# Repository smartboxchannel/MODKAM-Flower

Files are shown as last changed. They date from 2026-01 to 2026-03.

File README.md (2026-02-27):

# MODKAM Flower

## Открытый проект датчика влажности почвы MODKAM Flower v4

(основан на исходном коде проекта DIYRUZ Flower - https://github.com/diyruz/flower)

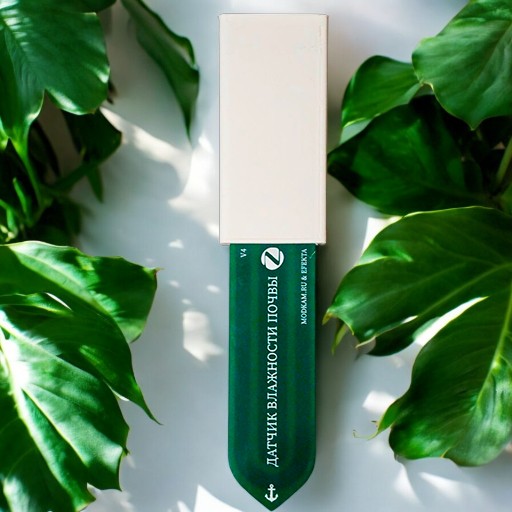
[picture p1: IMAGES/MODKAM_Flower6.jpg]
MODKAM Flower
 

Датчик, работает на базе SoC CC2530, основан на емкостном методе измерения (у датчика нет электрического контакта с почвой). Питание датчика осуществляется от батареек CR 2032 и AAA.

Печатная плата четырехслойная, с медным сенсором во внутреннем слое. Это решение обеспечивает долговечность. Медный сенсор со временем не коррозирует от проникающей влаги через микротрещины в маске, которые появляются со временем.

### Основные передаваемые данные:

Identify - идентификация устройства

Soil moisture - измеренное значение влажности почвы

Battery - оставшийся заряд в %

### Дополнительные передаваемые данные:

Temperature - измеренное значение температуры

Illuminance - измеренная освещенность(версия zFlora S Max)

Устройство может быть сконфигурировано внешними командами, отправляемыми через интерфейс контроллера умного дома. 

Что бы датчик получило конфигурационную команду, после отправки нового значения со страницы устройства в з2м, нужно нажать кнопку на датчике, он выйдет из сна, примет данные и запишет в энергонезависимую память.

### Конфигурационные команды:

Read sensors delay - время сна датчика, в минутах, по умолчанию 3 минуты

Smart sleep - Режим проверки устройством наличия для него пакетов на роутерах и координаторе

Lifetime - время работы датчика с момента прошивки

Tx radio power - Мощность радиопередатчика

Resolution - Разрешение сенсора DS18B20

Temperature compensation - Температурная компенсация

Lux factor - множитель для подстройки сенсора освещенности, диапазон 0.1-10.0, шаг 0.1.

#

### Ввод датчика в сеть, выход из сети
Для джойна (вход в сеть), нажать и удерживать кнопку 2 секунды, загорится светодиод, потухнет либо при начале входа в сеть, (в среднем через 5-8 секунд) либо через 15 секунд, что будет означать что датчик не нашел открытой сети.

На время ввода в сеть расположитесь не далеко от координатора (1-2 метра) или роутера с хорошим уровнем сигнала. 

Если вы не видите на вкладке свойства всех значений конфигурационных атрибутов(пустые поля, переключатели в неопределенном состоянии) или на странице отчеты нет строк о батарейке, температуре, то скорее всего конфигурация, которая следует сразу за интервью, не была пройдена до конца.

Для повторного прохождения конфигурации, перейдите на главную страницу z2m, найдите строку датчика и справа нажмите на кнопку - реконфигурация (желтая кнопка), после этого нажмите 2-5 раз кнопку на датчике с интервалом 1-2 секунды. При успешном прохождении конфигурации в интерфейсе з2м должно появится "всплывающее" сообщение об успешно пройденной реконфигурации. В разделе датчика, на вкладке свойства должны появится значения и установки всех конфигурационных свойств, на странице отчеты должны появится строки с конфигурационными настройками отчетов.

Для выхода из сети зажать кнопку на 10 секунд, по истечении этого времени загорится светодиод, кнопку можно отпустить. Датчик отправит сообщение о выходе из сети, сотрет у себя все настройки в памяти.

### Рекомендации
При начальном использовании датчика рекомендуется вставить датчик в грунт и обильно пролить. Что бы из почвы вокруг сенсора вышел воздух и грунт уплотнился. Если этого не сделать, то в первые 1-2 суток может наблюдаться более низкий уровень измеренной влажности, который к тому же может расти немного вверх.

### Тест сенсора влажности

Возьмите датчик в руку (держаться за батарейный отсек, не за плату!).

Не касаясь сенсора нажать кнопку - soil_moisture должно быть 0%.

Зажать второй рукой сенсор, или опустить сенсор в воду, нажать на кнопку - должно быть около больше 0% (в воде 100%).

#

Поблагодарить авторов: https://yoomoney.ru/fundraise/P2XLTgJsB6k.231012

Thank the authors: https://yoomoney.ru/fundraise/P2XLTgJsB6k.231012

Телеграм чат DIY Devices - https://t.me/diy_devices

Продажа DIY Устройств - https://t.me/diydevmart

#

### Установка среды разработки

В качестве среды разработки будет использоваться IAR Embedded Workbench, где цифра 8051 это архитектура чипа, а не версия системы, как можно подумать. Для начала необходимо ее [скачать по ссылке](https://www.iar.com/iar-embedded-workbench#!?architecture=8051)

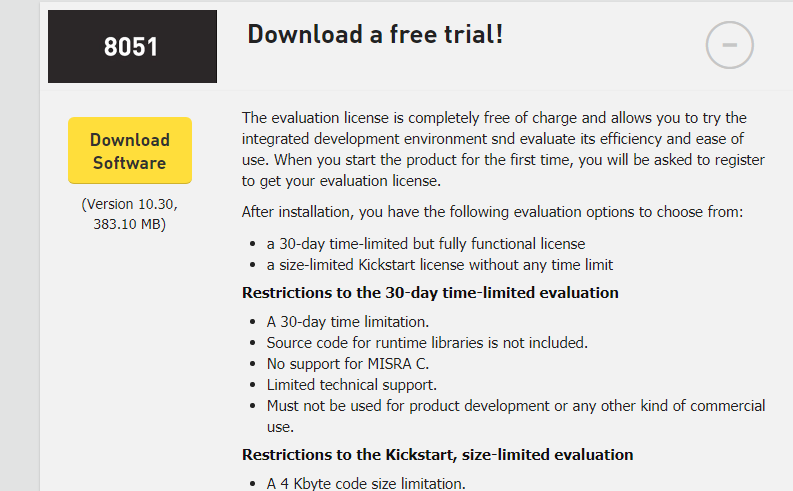
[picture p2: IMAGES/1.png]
 

Запускаем, необходимо выбрать пункт "Install IAR Embedded Workbench® for 8051"

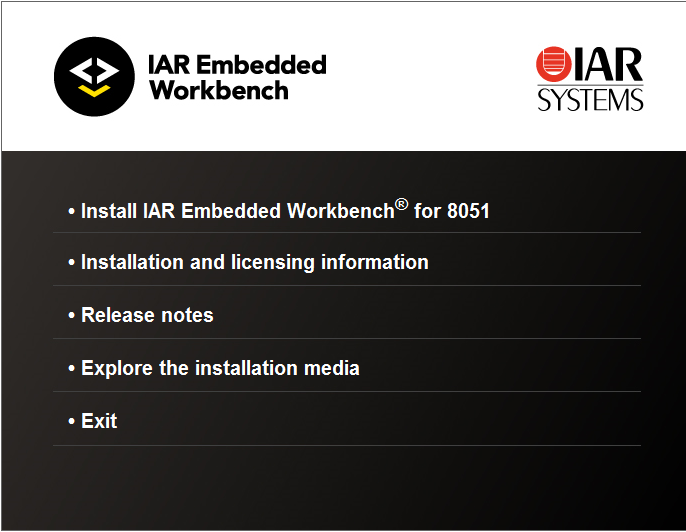
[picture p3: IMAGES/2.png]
 

При установке iar надо выбрать режим custom:

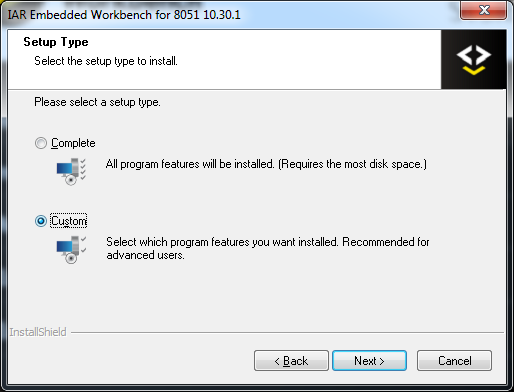
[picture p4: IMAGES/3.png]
 

и убрать галочку с установки Dongle drivers

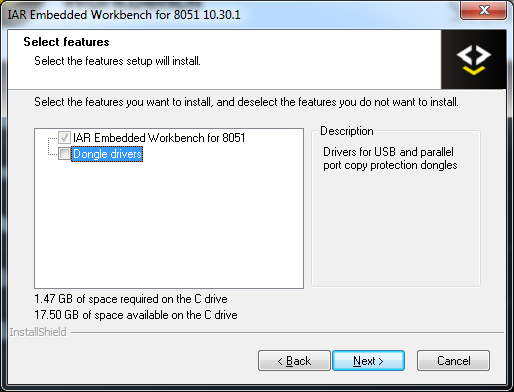
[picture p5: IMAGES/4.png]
 

При попытки запуска проекта может быть такая ошибка:

MODKAM Flower 

Поэтому перед запуском проекта необходимо убедиться что python установлен. Проверить это можно в командной строке:

python –-version

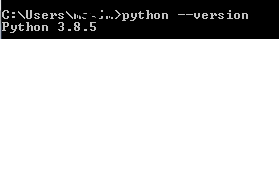
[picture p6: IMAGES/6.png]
 

Если все хорошо, то покажет текущую установленную версию python, как на примере:

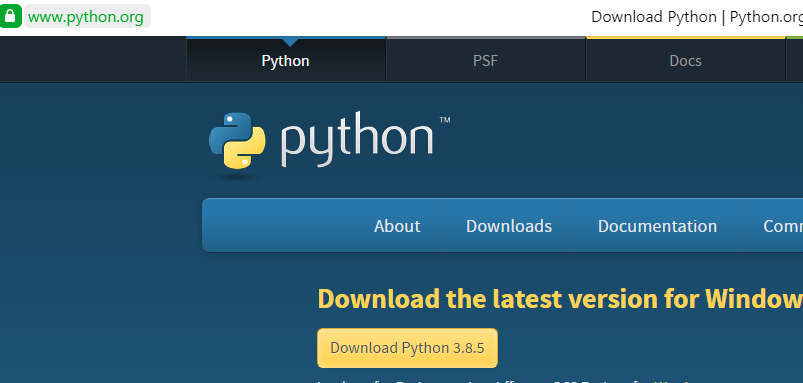
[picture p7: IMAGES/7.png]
 

Если же нет, то [идем устанавливать python](https://www.python.org/)

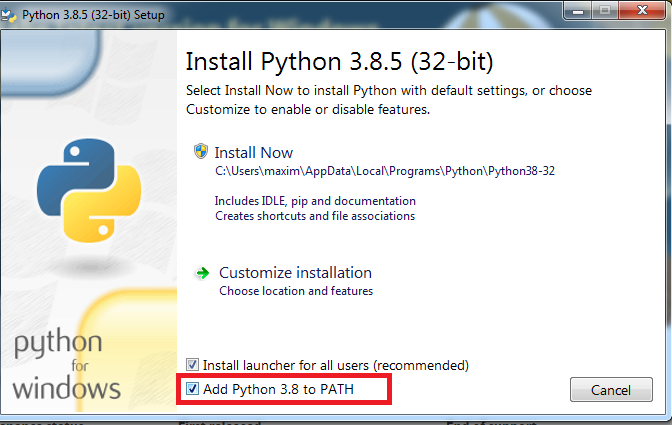
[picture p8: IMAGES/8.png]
 

Устанавливаем его. Обязательно необходимо проставить галочку "add python **** to path"

MODKAM Flower 

Устанавливаем прошивку [Z-Stack 3.0.2](https://www.ti.com/tool/Z-STACK) — это SDK для разработки прошивок.

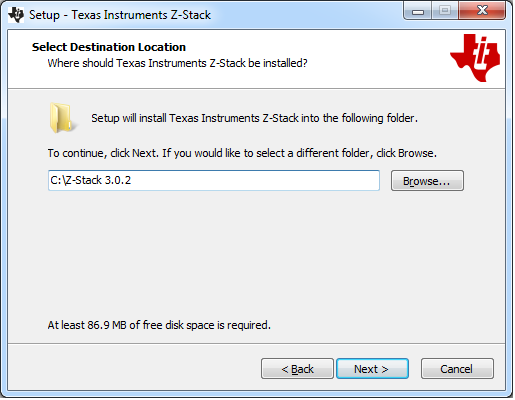
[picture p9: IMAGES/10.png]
 

Устанавливаем, можно немного уменьшить путь до zstack: C:\Z-Stack 3.0.2. 

Скачиваем исходный код из репозитория

Добавляем папку с файлами проекта в zstack: C:\Z-Stack 3.0.2\Projects\zstack\HomeAutomation

Теперь можно запускать IAR Embedded Workbench. Открываем проект пунктом меню Open workspace

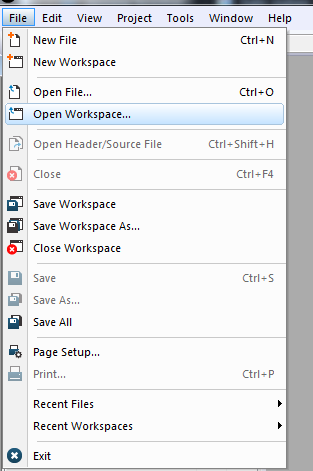
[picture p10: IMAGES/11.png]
 

Находим нашу папку со скаченным проектом, далее в папке CC2530DB находим файл проекта

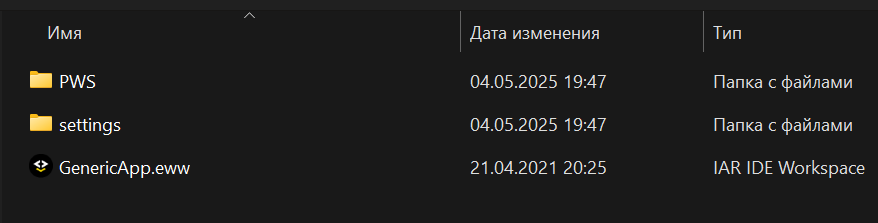
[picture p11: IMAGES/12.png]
 

Выполняем Rebuild All.

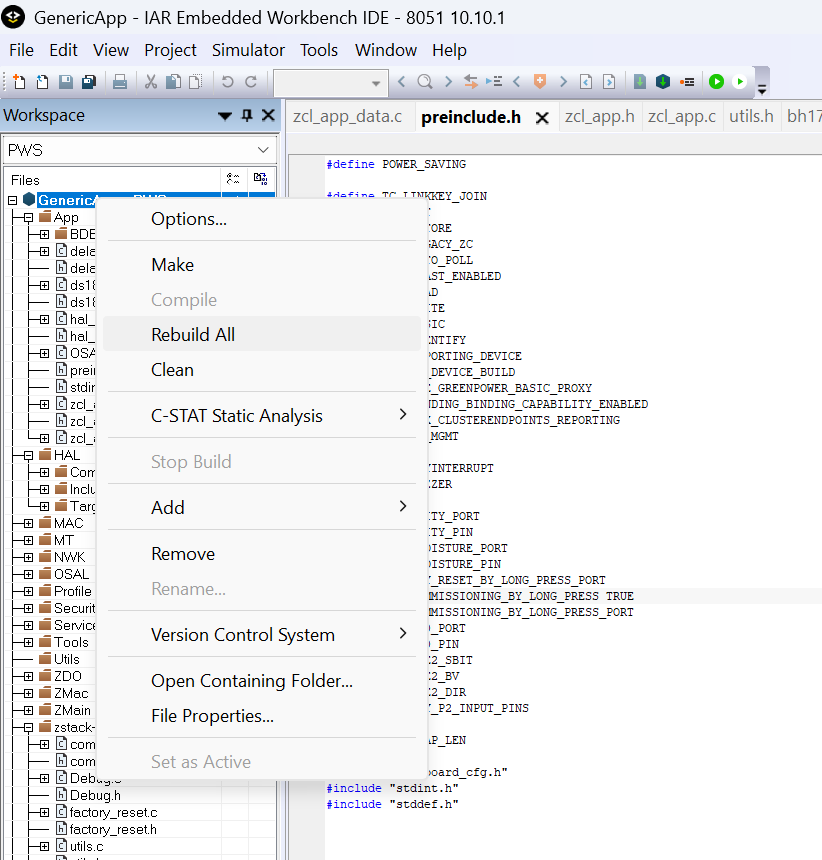
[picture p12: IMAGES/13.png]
 

#

### Как прошить устройство

Скачайте Smart RF Flash Programmer V1 https://www.ti.com/tool/FLASH-PROGRAMMER

Откройте приложение, выберите HEX-файл прошивки

Подключите устройство проводами к CCDebugger, сначала сотрите данные с чипа, затем прошейте его.

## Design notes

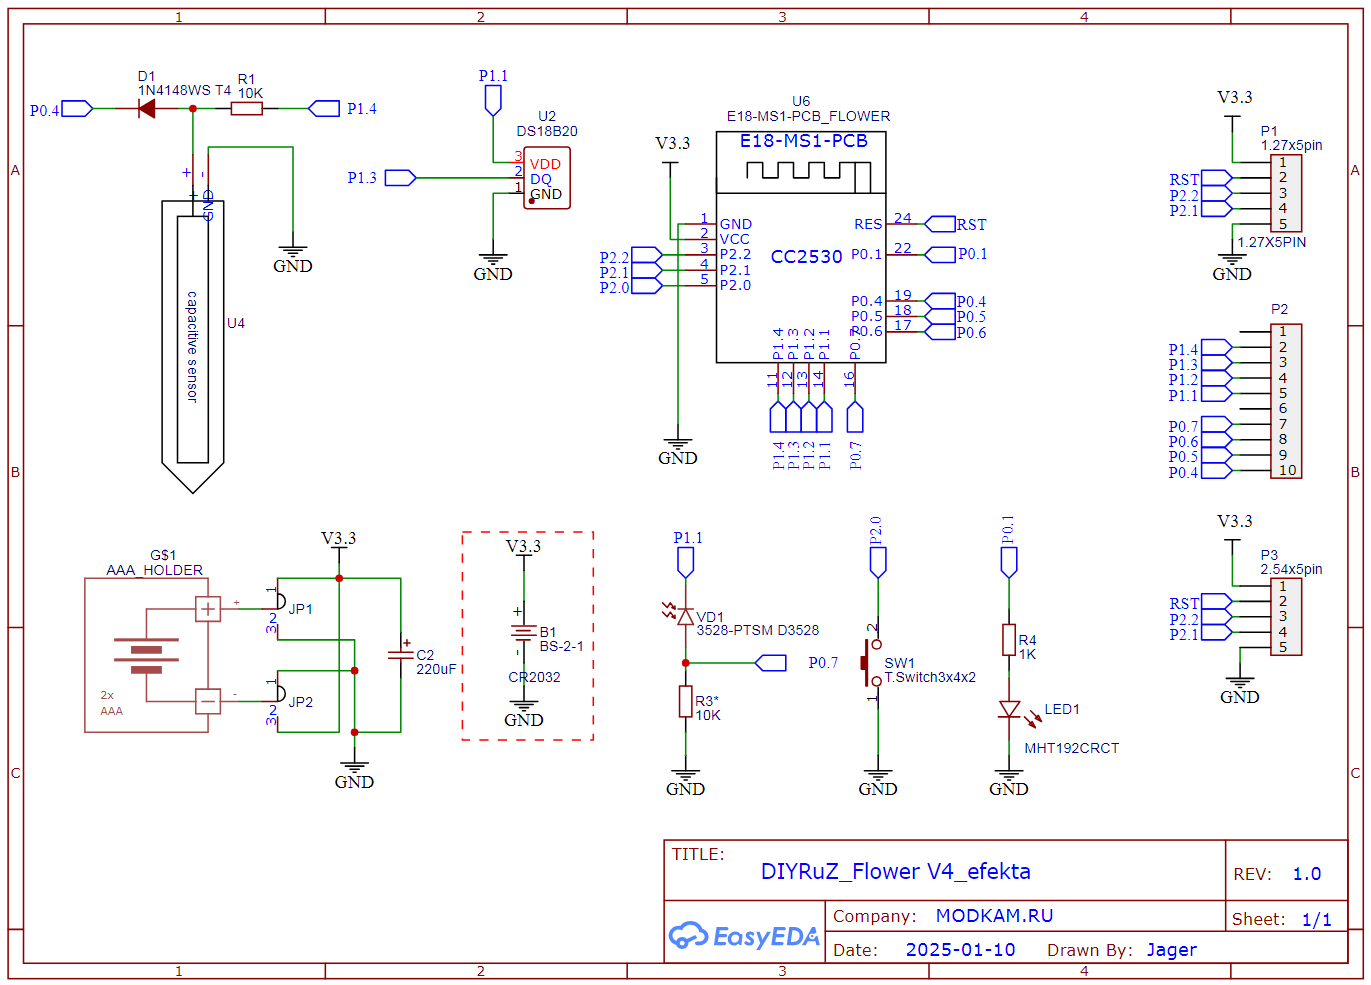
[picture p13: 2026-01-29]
SCHEMATIC/V4_efekta.png

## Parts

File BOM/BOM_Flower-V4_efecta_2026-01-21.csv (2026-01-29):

ID | Name | Designator | Footprint | Quantity | Manufacturer Part | Manufacturer | Supplier | Supplier Part | Price
1 | BS-2-1 | B1 | CR2032 | 1 | BS-2-1 | Q&J | LCSC | C70376 | 0.067
2 | 220uF | C2 | CAP-SMD_L7.3-W4.3-R-RD | 1 | TPSD227M010R0100 | AVX | LCSC | C8028 | 0.958
3 | 1N4148WS T4 | D1 | SOD-323_L1.8-W1.3-LS2.5-FD | 1 | 1N4148WS T4 | CJ | LCSC | C2128 | 0.009
4 | AAA_HOLDER | G$1 | AAA_HOLDER | 1
5 | SMD Jumper 3 | JP1,JP2 | SMD_JUMPER_3 | 2 | SMD Jumper 3
6 | MHT192CRCT | LED1 | LED 1206 | 1 | MHT192CRCT | MEIHUA | LCSC | C389517 | 0.022
7 | 1.27x5pin | P1 | 1.27X5PIN | 1 | 1.27x5pin | ReliaPro |  | C28952 | 0.053
8 | 1.27X10PIN | P2 | 1.27X10PIN | 1
9 | 2.54x5pin | P3 | DIP-1X5P-2.54MM | 1 | 1.27x5pin | ReliaPro |  | C28952 | 0.053
10 | 10K | R1,R3* | R0805 | 2 | 0603WAF1002T5E | UniOhm | LCSC | C25804 | 0.001
11 | 1K | R4 | R0805 | 1 | 0402WGF1001TCE | UniOhm | LCSC | C11702 | 0.001
12 | T.Switch3x4x2 | SW1 | SWITCH-3.0*4.0 | 1 | T.Switch3x4x2 | ReliaPro |  | C26638
13 | DS18B20 | U2 | TO-92-3_L4.9-W3.7-P1.27-L | 1 | DS18B20 | Youtai Semiconductor Co., Ltd. | LCSC | C376006 | 0.548
14 | capacitive sensor | U4 | CAPACITIVE SENSOR | 1
15 | E18-MS1-PCB_flower | U6 | E18-MS1-PCB_FLOWER | 1 | E18-MS1-PCB
16 | 3528-PTSM D3528 | VD1 | LED-SMD_L3.5-W2.8-LS3.6-RD | 1 | - | Shenzhen Jing Chuang He Li Tech | LCSC | C242256 | 0.104

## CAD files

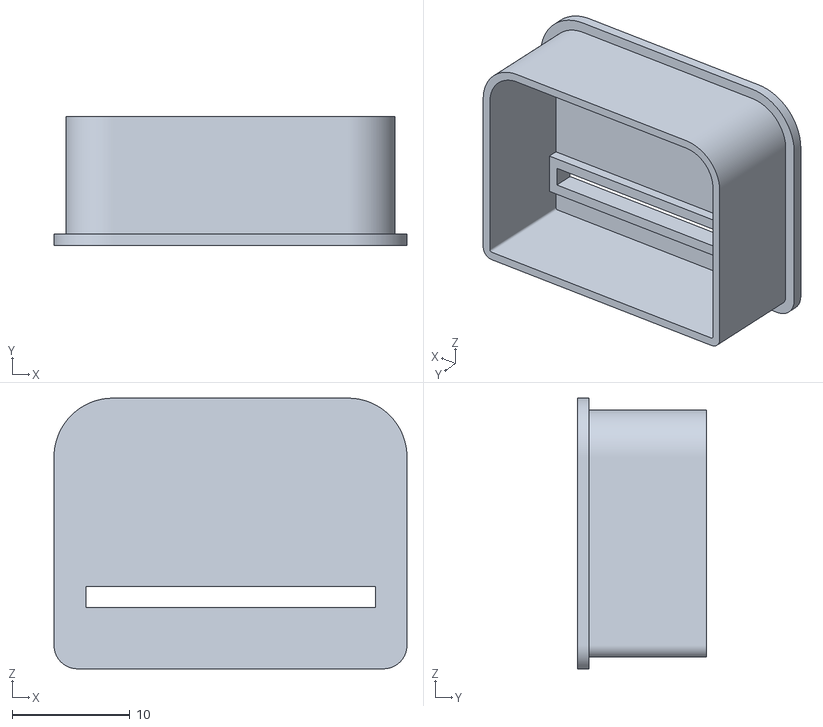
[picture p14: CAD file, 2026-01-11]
ENCLOUSER/2.STL
30.0 x 11.0 x 23.0

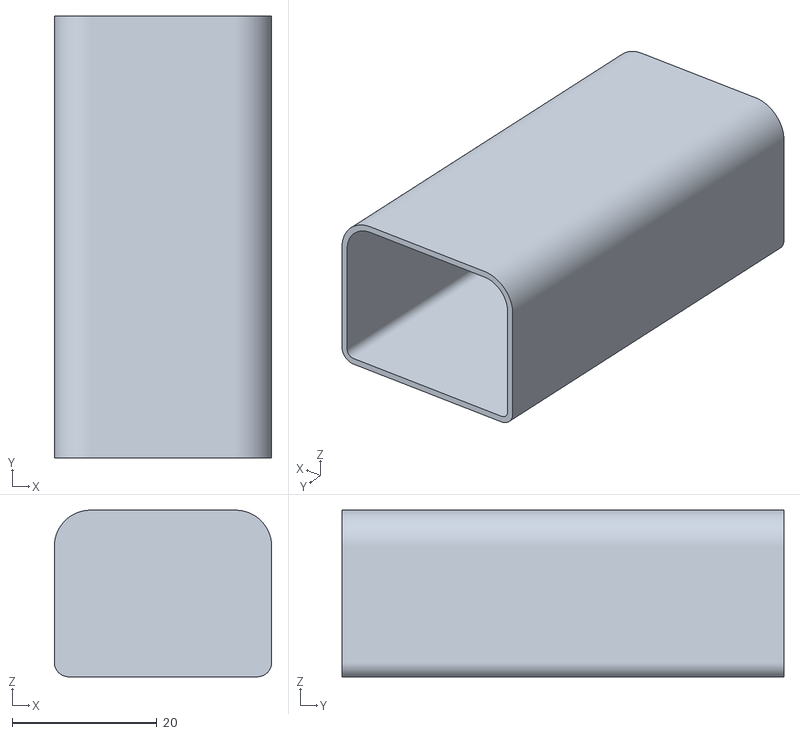
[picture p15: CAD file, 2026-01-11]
ENCLOUSER/1.STL
30.0 x 61.0 x 23.0

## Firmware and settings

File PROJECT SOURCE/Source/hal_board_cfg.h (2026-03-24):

#ifndef HAL_BOARD_CFG_H
#define HAL_BOARD_CFG_H

/*******************************************************************************************************
 *                                           Includes
 *******************************************************************************************************/

#include "hal_mcu.h"
#include "hal_defs.h"
#include "hal_types.h"

/*******************************************************************************************************
 *                                          Clock Speed
 *******************************************************************************************************/

#define HAL_CPU_CLOCK_MHZ     32

/* 32 kHz clock source select in CLKCONCMD */
#if !defined (OSC32K_CRYSTAL_INSTALLED) || (defined (OSC32K_CRYSTAL_INSTALLED) && (OSC32K_CRYSTAL_INSTALLED == TRUE))
#define OSC_32KHZ  0x00 /* external 32 KHz crystal oscillator */
#else
#define OSC_32KHZ  0x80 /* internal 32 KHz RC oscillator */
#endif

#define HAL_CLOCK_STABLE() 

/*******************************************************************************************************
 *                                         Key Release detect support
 *******************************************************************************************************/
#define HAL_KEY_CODE_NOKEY 0xff

/*******************************************************************************************************
 *                                       LED Configuration
 *******************************************************************************************************/

// TODO: review all HAL_BOARD_CC2530EB_REV17 and replace with HAL_BOARD_CC2530RC
//       if applicable.
#define HAL_NUM_LEDS            0

#define HAL_LED_BLINK_DELAY()   st( { volatile uint32 i; for (i=0; i<0x5800; i++) { }; } )
#define ACTIVE_LOW        !
#define ACTIVE_HIGH       !!    /* double negation forces result to be '1' */

/*******************************************************************************************************
 *                         OSAL NV implemented by internal flash pages.
 *******************************************************************************************************/

// Flash is partitioned into 8 banks of 32 KB or 16 pages.
#define HAL_FLASH_PAGE_PER_BANK    16
// Flash is constructed of 128 pages of 2 KB.
#define HAL_FLASH_PAGE_SIZE        2048
#define HAL_FLASH_WORD_SIZE        4

// CODE banks get mapped into the XDATA range 8000-FFFF.
#define HAL_FLASH_PAGE_MAP         0x8000

// The last 16 bytes of the last available page are reserved for flash lock bits.
// NV page definitions must coincide with segment declaration in project *.xcl file.
#if defined NON_BANKED
#define HAL_FLASH_LOCK_BITS        16
#define HAL_NV_PAGE_END            30
#define HAL_NV_PAGE_CNT            2
#else
#define HAL_FLASH_LOCK_BITS        16
#define HAL_NV_PAGE_END            126
#define HAL_NV_PAGE_CNT            6
#endif

// Re-defining Z_EXTADDR_LEN here so as not to include a Z-Stack .h file.
#define HAL_FLASH_IEEE_SIZE        8
#define HAL_FLASH_IEEE_PAGE       (HAL_NV_PAGE_END+1)
#define HAL_FLASH_IEEE_OSET       (HAL_FLASH_PAGE_SIZE - HAL_FLASH_LOCK_BITS - HAL_FLASH_IEEE_SIZE)
#define HAL_INFOP_IEEE_OSET        0xC

#define HAL_FLASH_DEV_PRIVATE_KEY_OSET     0x7D2
#define HAL_FLASH_CA_PUBLIC_KEY_OSET       0x7BC
#define HAL_FLASH_IMPLICIT_CERT_OSET       0x78C

#define HAL_NV_PAGE_BEG           (HAL_NV_PAGE_END-HAL_NV_PAGE_CNT+1)
// Used by DMA macros to shift 1 to create a mask for DMA registers.
#define HAL_NV_DMA_CH              0
#define HAL_DMA_CH_RX              3
#define HAL_DMA_CH_TX              4

#define HAL_NV_DMA_GET_DESC()      HAL_DMA_GET_DESC0()
#define HAL_NV_DMA_SET_ADDR(a)     HAL_DMA_SET_ADDR_DESC0((a))

/*******************************************************************************************************
 *  Serial Boot Loader: reserving the first 4 pages of flash and other memory in cc2530-sb.xcl.
 *******************************************************************************************************/

#define HAL_SB_IMG_ADDR       0x2000
#define HAL_SB_CRC_ADDR       0x2090
// Size of internal flash less 4 pages for boot loader, 6 pages for NV, & 1 page for lock bits.
#define HAL_SB_IMG_SIZE      (0x40000 - 0x2000 - 0x3000 - 0x0800)

/*******************************************************************************************************
 *                                            Macros
 *******************************************************************************************************/

/* ----------- RF-frontend Connection Initialization ---------- */
#if defined HAL_PA_LNA_CC2592
extern void MAC_RfFrontendSetup(void);
#define HAL_BOARD_RF_FRONTEND_SETUP() MAC_RfFrontendSetup()
#else
#define HAL_BOARD_RF_FRONTEND_SETUP()
#endif
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

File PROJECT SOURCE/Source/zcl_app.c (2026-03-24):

/*********************************************************************
 * INCLUDES
 *********************************************************************/

#include "AF.h"
#include "OSAL.h"
#include "OSAL_Clock.h"
#include "OSAL_PwrMgr.h"
#include "ZComDef.h"
#include "ZDApp.h"
#include "ZDNwkMgr.h"
#include "ZDObject.h"
#include "math.h"
#include "nwk_util.h"
#include "zcl.h"
#include "zcl_app.h"
#include "zcl_diagnostic.h"
#include "zcl_general.h"
#include "zcl_ms.h"
#include "bdb.h"
#include "bdb_interface.h"
#include "gp_interface.h"
#include "OnBoard.h"
#include "stdio.h"
#include "stdlib.h"

#include "hal_adc.h"
#include "hal_drivers.h"
#include "hal_key.h"
#include "hal_led.h"
#include "commissioning.h"
#include "factory_reset.h"
#include "utils.h"
#include "ds18b20.h"
#include "delay.h"

/*********************************************************************
 * MACROS
 *********************************************************************/

#define HAL_KEY_CODE_RELEASE_KEY                                                HAL_KEY_CODE_NOKEY
#define MULTI                                                                   (float)0.428
#define VOLTAGE_MIN                                                             2.1
#define VOLTAGE_MAX                                                             3.2
#define ZCL_BATTERY_REPORT_REPORT_CONVERTER(millivolts)                         getBatteryRemainingPercentageZCLCR2032(millivolts)

#define DS18B20_TEMP_9_BIT                                                      0x1F
#define DS18B20_TEMP_10_BIT                                                     0x3F
#define DS18B20_TEMP_11_BIT                                                     0x5F
#define DS18B20_TEMP_12_BIT                                                     0x7F
#define TEMPDEF                                                                 250

#define START_PWS()                                                                                                                 \
    do {                                                                                                                            \
        st(T3CTL |= BV(4););                                                                                                        \
    } while (0)
#define STOP_PWS()                                                                                                                  \
    do {                                                                                                                            \
        st(T3CTL &= ~BV(4); T3CTL |= BV(2););                                                                                       \
    } while (0)
      
#define START_SENS()                                                                                                                \
    do {                                                                                                                            \
        HAL_TURN_ON_LED4();                                                                                                         \
        IO_PUD_PORT(DS18B20_PORT, IO_PUP);                                                                                          \
    } while (0)
#define STOP_SENS()                                                                                                                 \
    do {                                                                                                                            \
        HAL_TURN_OFF_LED4();                                                                                                        \
        ONEWIRE2_SBIT = 0;                                                                                                          \
        IO_PUD_PORT(DS18B20_PORT, IO_PDN);                                                                                          \
    } while (0)

/*********************************************************************
 * GLOBAL VARIABLES
 *********************************************************************/

extern bool requestNewTrustCenterLinkKey;
byte zclApp_TaskID;

int16 sendInitReportCount = 0;
uint8 resolution = DS18B20_TEMP_12_BIT;
bool blockButton = false;
bool butt = false;

static bool pushBut = false;
static bool pushBat = false;
static bool initOut = false;
static bool mode1_old = false;
static bool comparisonPreviousData3_old = false;
static uint8 currentSensorsReadingPhase = 0;
static uint8 resolution_old = 0;
static int8 txPower_old = 0;
static int16 temp_old = 0;
static int16 tempTr = 33;
static int16_t tempreal;
static int16 lum_old = 0;
static int16 lumTr = 50;
static int16 illumCoof_old = 0;
static uint32 reportDelay_old = 0;
static uint32 readPause = 50;

uint8 SeqNum = 0;
afAddrType_t inderect_DstAddr = {.addrMode = (afAddrMode_t)Addr16Bit, .endPoint = 1, .addr.shortAddr = 0};

/*********************************************************************
 * LOCAL FUNCTIONS PROTOTYPES
 *********************************************************************/

static ZStatus_t zclApp_ReadWriteAuthCB(afAddrType_t *srcAddr, zclAttrRec_t *pAttr, uint8 oper);   
static void zclApp_ProcessIdentifyTimeChange(uint8 endpoint);
static void zclBattery_Report(void);
static void zclApp_HandleKeys(byte shift, byte keys);
static void zclApp_Report(void);
static void zclApp_BasicResetCB(void);
static void zclApp_RestoreAttributesFromNV(void);
static void zclApp_SaveAttributesToNV(void);
static void zclApp_ReadSensors(void);
static void zclApp_ReadSendBatt(void);
static void zclApp_ReadSoilHumidity(void);
static void zclApp_sendLocalTime(void);
static void zclApp_ReadLumosity(void);
static void zclApp_InitPWM(void);
static void zclApp_sendTemperature(void);
static void zclApp_sendLumi(void);
static void zclApp_sendSoilHumidity(void);
static void zclApp_sendSoilHumidity2(void);
static void zclApp_DS18B20_RS(void);
static void zclApp_LedOn(void);
static void zclApp_LedOff(void);
static uint16 getBatteryVoltage(void);
static uint8 getBatteryVoltageZCL(uint16 millivolts);
static uint8 getBatteryRemainingPercentageZCLCR2032(uint16 volt16);
static void zclBattery_Report(void);
static void zclBattery_Read(void);

/*********************************************************************
 * ZCL General Profile Callback table
 *********************************************************************/
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
